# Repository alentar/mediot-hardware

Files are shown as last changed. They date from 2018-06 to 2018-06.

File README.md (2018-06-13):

# RPMS-hardware

## Intro

**MedIOT** project uses the NodeMCU as main embedded system. It is selected nodeMCU as the main platform because it contains an integrated ESP8266MOD wifi module with Arduino nano board. A digital temperature sensor DS18B20 sensor and Pulse sensor is using as inputs to the nodemodule.

## Before get started

 1. Install [Arduino SDK](https://www.arduino.cc/en/Main/Software) and [ESP8266 Board Manager](https://github.com/esp8266/Arduino#installing-with-boards-manager)
 
 3. Install following Arduino libraries by `Sketch>Library>Library Manager` ;
	 - Arduino JSON- (by Benoit Blanchan) [Link](https://arduinojson.org/?utm_source=meta&utm_medium=library.properties)
	 - Arduino Mqtt (by Oleg Kevolenko) - [Link](https://github.com/monstrenyatko/ArduinoMqtt)
	 - Arduino LCD I2C Lib - [Link](https://github.com/fdebrabander/Arduino-LiquidCrystal-I2C-library)
	 
 4.  Set the sketch option from `Tools` menu as follows 
 

## Board Configuration
 In this, we are using two sensors, Heart Pulse sensor and Temperature sensor. Pulse sensor is given to A0 input, and Temperature sensor DS18B20 given to GPIO input

For `ESP.Restart()` nodemcu checking the pins for booting. Here we are **boot from the sketch**  So according to the following table  **GPIO0** and **GPIO1** should connected to **3V3 Vcc** and **GPIO15** should connected to **GND** with resistors . 

> if the wdt reset is triggert the board reboots, when it **reboots it
> is checking the state of GPIO0 and GPIO15 and GPIO2**

|GPIO15|GPIO0|GPIO2|Mode|
|--|--|--|--|
|0V|0V|	3.3V|Uart Bootloader||
|0V|3.3V|3.3V|**Boot sketch**||
|3.3V|x|x|SDIO mode (not used for Arduino)|

> **you need to make sure that the pins in the right state when a wtd happens or you call ESP.restart() better you add some delays to
> prevent the wtd from triggering.**

**`Important :
All the above connetions should be made with a 10K resistors`**

## Run the code

 1. Compile and Upload the code to the Nodemcu
 2. Open SerialMonitor
 3. Restart the Nodemcu 
 4. SoftAP WiFi is set on the relevent ip address shown in the serial monitor. *default WiFi SSID*-> `Mediot1`

##  API End Points
API end points of the Sever as follows;

 #### Server default Address: `192.168.4.1:8080`
-----
### Show Server Status

Get the status of the server.

**URL** : `/api/status/`

**Method** : `GET`

**Auth required** : NO

**Permissions required** : None

 Success Response

**Code** : `200 OK`
```json
{
    "status": "ok"
}
```

---
### Set Configurations

Setting the WiFi credentials and API end point of the mqtt server

**URL** : `/api/config/`

**Method** : `POST`

**Auth required** : --

**Permissions required** : --

**Data constraints**

Provide wifi details and api end point.

```json
{
	"ssid":"YOURWIFISSID",
	"password":"YOURWIFIPASSWORD",
	"link":"MQTT_SERVER"
}
```

### Success Response

**Code** : `200 OK`
```json
{
    "status": "ok"
}
```
---
### Save Configuration

Saving the given wifi credentials and end point

**URL** : `/api/finish`

**Method** : `GET`

**Auth required** : NO

**Permissions required** : None

 Success Response

**Code** : `200 OK`
```json
{
    "status": "ok"
}
```

## Board Schemetics

### Schemetic Design

schem

### PCB Design

final

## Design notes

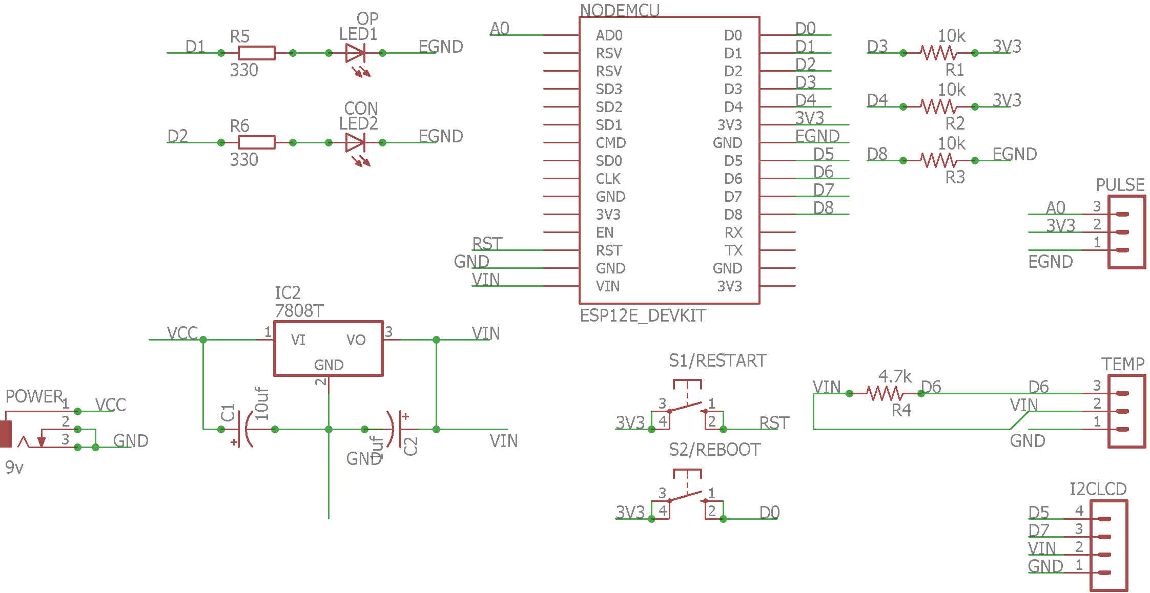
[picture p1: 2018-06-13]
PCB/schem.png

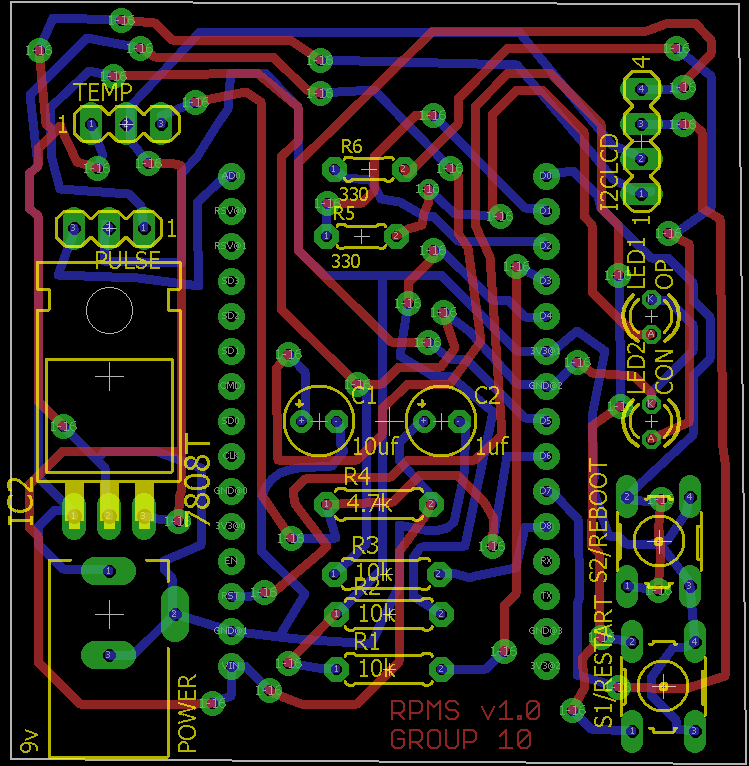
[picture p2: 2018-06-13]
PCB/final.png

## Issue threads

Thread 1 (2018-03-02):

NodeMCU configuration

kasvith, 2018-03-02:
# Problem

NodeMCU should be configured before using the actual web server provided by **mediot**.
This requires achieving followings

- Setup a prefered **SSID** and **Password**  for NodeMCU
- Setup provided Server Url(preferably for **HOST_URI**) by staff

# Solution

These items need to be saved on NodeMCU for continue process.
When you successfully connected to a WiFi NodeMCU will automatically save them in storage and when it restarts it will use previous credentials.

So it only requires to store **HOST_URI** itself on the **EEPROM**. Others are take care by **WiFi** module of **NodeMCU**.

So its required a way to start the Hotspot(aka AccessPoint or AP) of the NodeMCU. Preferably using a **Button**.

## Workflow of Proposed Solution

- Power on NodeMCU
- **Press Button** to **Start Configuration Mode**
- Password and SSID of this Hotspot is given to Staff
- The hotspot will start a simple webserver(RESTful) on **192.168.4.1**
- Staff will use an App after connecting this Hotspot and it will look for **192.168.4.1**.
- Once connected user can set above information with server
- Once finished User may exit Configuration Mode by selecting **Finish** on the App
- This may trigger NoduMCU to stop AccessPoint mode and try to connect given SSID and then send HTTP requests for **HOST_URI** (which set by user)
- Once connected the NodeMCU should show the status of the connection by indicating via LED so staff knows whether setup was successful

# Requirement
- NodeMCU with AccessPoint Mode
- For development purposes use **PostMan**
- NodeMCU should have a field called **SerialNo** which is used by server to provision the device.

kasvith, 2018-03-02:
@edussuriyac @namila007 any comments ?

kasvith, 2018-03-02:
Refer my code for webserver

namila007, 2018-03-02:
starting working on this now . first i have to look up more details about this

Closed 2018-03-18.

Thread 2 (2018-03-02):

Need an Andoid Application for Configurations

kasvith, 2018-03-02:
# Problem
We are creating a NodeMCU Configuration Module in #1
We need a way to communicate with this, so we need to create a App to connect with this **RESTful API**.

# Requirenments
- NodeMCU will start its AccessPoint and user will connect to that with provided password
- Then he opens the App (**Mediot Config** would be fine)
- App will connect to server listens on **192.168.4.1** of the current network (hosted by NodeMCU)
- App will use JSON API to connect and configure followings
  - **SSID**
  - **Password**
  - **Host URI**
- After successfully setting these up, App may exit by touching a button called **Save and Exit**, this will trigger server to terminate itself and start again with provided configurations (you will get an API endpoint for that)

@namila007 must provide a detailed API documentation in **Wiki** Section so @edussuriyac can use them correctly

Meanwhile application can be developed

kasvith, 2018-03-02:
Moved into separate repo

Closed 2018-03-02.

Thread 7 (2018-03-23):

Device authentication

kasvith, 2018-03-23:
This need to be done by sending a request to server with proper information about device. Once authorized server will issue mqtt topics for the device which can be used to connect and send data

**Server endpoints are on the way**

namila007, 2018-05-27:
already done. closes #12

Closed 2018-05-27.

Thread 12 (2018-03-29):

Device Authorization

namila007, 2018-03-29:
Creating device authorization;
RPMS server has a clean device management system. Before any device connect and publish data to server, they need to register themselves to the service.

Endpoint
`POST /api/devices/auth/self`

Sample Request
```json
{
	"mac": "<MACADDRESS OF THE DEVICE>",
	"chipId": "<CHIP ID IF AVALIABLE>"
}
```
mac is the required field here You can poll with server sending above information and based on status determine your next action

wiki link :[ LINK](https://github.com/alentar/rpms-server/wiki/Device-Authorization)

namila007, 2018-05-27:
closes #16

Closed 2018-05-27.

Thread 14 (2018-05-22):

MQTT Connection

namila007, 2018-05-22:
After authorizing the device, it must send to relevant mqqt broker with temp and heart data

Closed 2018-05-27.

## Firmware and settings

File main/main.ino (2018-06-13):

#include <ESP8266WiFi.h>
#include <WiFiClient.h>
#include <ESP8266WebServer.h>
#include <ArduinoJson.h>
#include <EEPROM.h>
#include <String.h>
#include "FS.h"
#include <MQTTClient.h>
#include <OneWire.h>
#include <DallasTemperature.h>
#include <LiquidCrystal_I2C.h>
#include <Wire.h>


#define HEARTPIN A0
#define GREENLED D1
#define REDLED D2
#define ONE_WIRE_BUS D6



const char *AUTH_SELF = "";

char ST_SSID[20];
char ST_PASSWORD[20];
char ST_LINK[20];
char CLIENT_ID[30];
char TOPIC[100];

/* Set these to your desired credentials. */
const char *ssid = "Mediot1";
const char *password = "randompassword";
const char *deviceID = "mediot";


OneWire oneWire(ONE_WIRE_BUS);
DallasTemperature sensors(&oneWire);
LiquidCrystal_I2C lcd(0x3F, 16, 2);  //SDL 7 SCL 5

typedef struct t  {
    unsigned long tStart;
    unsigned long tTimeout;
}timer;

timer pulse_timer = {0, 1000}; //Run every 1 seconds for pulse sensor.
timer temp_timer = {0, 5000}; //5sec for temp

  int UpperThreshold = 518;
  int LowerThreshold = 490;
  int reading = 0;
  bool IgnoreReading = false;
  bool FirstPulseDetected = false;
  unsigned long FirstPulseTime = 0;
  unsigned long SecondPulseTime = 0;
  unsigned long PulseInterval = 0;

MQTTClient client;
WiFiClient wificlient;


/*definitions

*/
void handleStatus();
void handleNotFound();
bool handleSetup();
void handleFinishWizard();
void sendError(char *message, int status);
void configureSoftAP();

bool checkEEPROM();
bool loadConfig();
void EEPROM_wifidata();
bool stationMode();

void mqtt_connect();
boolean authorize();

float getHeartRate();
void sendPulse (float bpm);
void sendTemp(float temp);
float getTemp();
void clearPrintingdigits(int col,int row);
/*
   END OF DEFINITIONS
*/



ESP8266WebServer server(8080);



void setup() {
  //starting eeprom and serial
  Serial.begin(115200);
  EEPROM.begin(512);  //in node EEPROM should init and EEPROM.commit to write.

  pinMode(GREENLED,OUTPUT);
  pinMode(REDLED,OUTPUT);

  Wire.begin(13,14); //Wire.begin(int sda, int scl);
  lcd.begin();   // initializing the LCD
  lcd.backlight(); // Enable or Turn On the backlight
  lcd.setCursor(4, 0);
  lcd.print("RPMS v1.1"); 
  lcd.setCursor(0, 1);
  lcd.print("LOADING...."); // Start Printing
  
  Serial.println("Mounting FS...");
  if (!SPIFFS.begin()) {
    Serial.println("Failed to mount file system");
    return;
  }
  Serial.setDebugOutput(true); //setting debug mode on
   digitalWrite(REDLED,HIGH);
  if (!checkEEPROM()) {
    //starting the AP   
    lcd.setCursor(0, 1);
    lcd.print("CONFIG MODE"); // config mode
    configureSoftAP();

    while (checkEEPROM() != true) {
      //we need to run the sever till the client writes the data to EEPROM
      server.handleClient();
      delay(3000);
    }
    //closing the AP

    WiFi.disconnect();
    WiFi.softAPdisconnect();
    EEPROM.end();
    delay(100);
  }
  else {
    Serial.println("HAS DATA ");
    
    lcd.setCursor(0, 1);
    lcd.print("LOADING CONFIG"); // Start Printing
  
    if (!loadConfig()) {
      Serial.println("Failed to load config file");
    } else {
      Serial.println("Config loaded");
    }
    delay(1000);
    if (!stationMode()) {
      Serial.println("Failed to start Stationary mode");
    } else {
      Serial.println("Stationary mode started");
    }

    //starting MQTT
    
    while (!authorize()){
      delay(500);//client sending post
    }

    sensors.begin(); //start temp sensor
    client.begin(ST_LINK, wificlient); //conecting to mqtt broker

    
  }

}

void loop() {
  
  
    //lcd.clear();
  
   
    delay(50);
    float bpm = (float)getHeartRate();
    float temp = getTemp();
    Serial.println(bpm);
     
  client.loop();
  if (!client.connected()) {
    mqtt_connect();
  }

  
  //lcd.clear();
  if (tCheck(&pulse_timer)) {
     Serial.println(bpm);
     
     lcd.setCursor(0, 0);
      lcd.print("BPM : ");
      clearPrintingdigits(6,0);
      lcd.setCursor(6, 0);
      lcd.print(bpm);
      sendPulse(bpm);
      
      tRun(&pulse_timer);
    }

    if (tCheck(&temp_timer)) {
     
     Serial.println(temp);
      lcd.setCursor(0, 1);
      lcd.print("TEMP: ");
      clearPrintingdigits(6,1);
      lcd.setCursor(6, 1);
      lcd.print(temp);
      sendTemp(temp);
      tRun(&temp_timer);
    }      
    //Serial.println(bpm);

  
  

}

void clearPrintingdigits(int col,int row){
  for(int i=col;i<17;i++){
    lcd.print("");
  }
  
}



/* Sensors
 *  
 */

void sendTemp(float temp){
  Serial.print("send temp: ");
  Serial.println(temp);
  String topic = TOPIC;
  topic += "/type/temperature";
  client.publish(topic, (String)temp);
}

float getTemp() {
  sensors.requestTemperatures();
  return (sensors.getTempCByIndex(0));
}


void sendPulse (float bpm) {
  //This executes every 1000ms.
 
  
  Serial.print("send");
  Serial.println(bpm);
  String topic = TOPIC;
  topic += "/type/bpm";
  client.publish(topic, (String)bpm);
}

bool tCheck (timer *t ) {
  if (millis() > t->tStart + t->tTimeout) {
    return true;    
  }
  return false;
}

void tRun (timer *t) {
    t->tStart = millis();
}

float getHeartRate(){
 

    reading = analogRead(HEARTPIN); 

      // Heart beat leading edge detected.
      if(reading > UpperThreshold && IgnoreReading == false){
        if(FirstPulseDetected == false){
          FirstPulseTime = millis();
          FirstPulseDetected = true;
        }
        else{
          SecondPulseTime = millis();
          PulseInterval = SecondPulseTime - FirstPulseTime;
          FirstPulseTime = SecondPulseTime;
        }
        IgnoreReading = true;
      }

      // Heart beat trailing edge detected.
      if(reading < LowerThreshold){
        IgnoreReading = false;
      }  

      float BPM = (1.0/PulseInterval) * 60.0 * 1000;

      return BPM;

  
}


/*
 * END OF HEART RATE
 */




/*
   Device IDs
*/
boolean authorize() {

  String device_id = String(ESP.getChipId());
  String mac_id = String(WiFi.macAddress());          //Get the response payload

  lcd.clear();
  lcd.setCursor(4, 0);
  lcd.print("RPMS v1.1"); 
  lcd.setCursor(0, 1);
  lcd.print("DEVICE AUTH"); 

  const int httpPort = 3000;
  String host = "192.168.8.100";
  String data = "{\"mac\":\"" + mac_id + "\",\"chipId\":\"" + device_id + "\"}";
  String buffer;
  char json[1000];

  // String* host = ST_LINK;
  if (!wificlient.connect(ST_LINK, httpPort)) {
    Serial.println("connection failed");
    delay(500);
    return false;
  }
  
  Serial.println("Requesting POST: ");
  // Send request to the server:
  wificlient.println("POST /api/devices/auth/self HTTP/1.1");
  wificlient.print("Host: ");
  wificlient.println(ST_LINK);
  wificlient.println("User-Agent: Arduino/1.0");
  wificlient.println("Connection: close");
  wificlient.println("Accept: */*");
  wificlient.println("Content-Type: application/json");
  wificlient.print("Content-Length: ");
  wificlient.println(data.length());
  wificlient.println();
  wificlient.print(data);

  delay(100); // Can be changed
  int counter = 0;

  char results[1500];
  char c ;
  int index = 0;
  while (wificlient.available())
  {
    c = wificlient.read();
    results[index] = c;
    index++;
  }
  results[index] = '\0';
  //Serial.println(results);
  int j = 0;
  for (int i = 430; i < index; i++) {
    json[j] = results[i];
    j++;
  }
  json[j] = '\0';

  Serial.println("closing connection");
  
  const size_t bufferSize = JSON_OBJECT_SIZE(3) + 70;
  DynamicJsonBuffer jsonBuffer(bufferSize);
  JsonObject& root = jsonBuffer.parseObject(json);

  const char* state = root["state"];
  const char* operate = "operate";

 // root.printTo(Serial);
  
  if (strcmp(state, operate) == 0) {
    lcd.clear();
    lcd.setCursor(4, 0);
    lcd.print("RPMS v1.1"); 
    lcd.setCursor(0, 1);
    lcd.print("AUTHORIZED"); 
    
    const char* mqttTopic = root["mqttTopic"];
    const char* id = root["id"];
    Serial.println(mqttTopic);
    strcpy(TOPIC, mqttTopic);
    strcpy(CLIENT_ID, id);
    Serial.println(TOPIC);
    delay(1000);
    return true;
  }else{
    delay(4000);
    return false;
  }
  delay(4000);
  return false;




}




/*
   End Device IDs
*/

/*
   START OF STATION MODE
*/
bool checkEEPROM() {

  int mem_loc = 0;
  int value;
  EEPROM.get(mem_loc, value);

  if (value == 1) {
    return true;
  } else {
    return false;
  }
}

bool loadConfig() {
  File configFile = SPIFFS.open("/config.json", "r");
  if (!configFile) {
    Serial.println("Failed to open config file");
    return false;
  }

  size_t size = configFile.size();
  if (size > 1024) {
    Serial.println("Config file size is too large");
    return false;
  }

  // Allocate a buffer to store contents of the file.
  std::unique_ptr<char[]> buf(new char[size]);


  configFile.readBytes(buf.get(), size);

  StaticJsonBuffer<200> jsonBuffer;
  JsonObject& json = jsonBuffer.parseObject(buf.get());

  if (!json.success()) {
    Serial.println("Failed to parse config file");
    return false;
  }

  
  
  json.printTo(Serial);
  const char* ssid = json["ssid"];
  const char*  pass = json["password"];
  const char*  link = json["link"];
  delay(10);
  strcpy(ST_PASSWORD, pass);
  strcpy(ST_LINK, link);
  strcpy(ST_SSID, ssid);
  delay(10);

  Serial.print("Loaded ssid: ");
  Serial.println(ST_SSID);
  Serial.print("Loaded password: ");
  Serial.println(ST_PASSWORD);
  Serial.print("Loaded link: ");
  Serial.println(ST_LINK);
  return true;
}

bool stationMode() {
  WiFi.disconnect();
  WiFi.softAPdisconnect();
  delay(100);
  WiFi.persistent(false);
  WiFi.mode(WIFI_OFF);
  WiFi.mode(WIFI_STA);
  if (WiFi.begin(ST_SSID, ST_PASSWORD)) {
    return true;
  } else {
    return false;
  }

}


/*
   END OF STATION MODE
*/






/*             Start of WIFI SERVER
  /api/status for check
  /api/config for configurations
  /api/finish/wizard for end

*/
void configureSoftAP() {
  //dc all
  WiFi.disconnect();
  WiFi.softAPdisconnect();

  Serial.println();
  Serial.print("Configuring access point...");
  /* You can remove the password parameter if you want the AP to be open. */
  WiFi.mode(WIFI_AP);
  delay(100);

  Serial.println(WiFi.softAP(ssid) ? "Ready" : "Failed!");

  IPAddress myIP = WiFi.softAPIP();
  Serial.print("AP IP address: ");
  Serial.println(myIP);
  server.on("/api/status", handleStatus);
  server.on("/api/config", handleSetup);
  server.on("/api/finish", handleFinishWizard);
  server.onNotFound(handleNotFound);
  server.begin();
  Serial.println("HTTP server started");
}


void handleStatus() {
  StaticJsonBuffer<300> JSONbuffer;   //Declaring static JSON buffer
  JsonObject& JSONencoder = JSONbuffer.createObject();

  JSONencoder["status"] = "OK";
  char JSONmessageBuffer[300];
  JSONencoder.prettyPrintTo(JSONmessageBuffer, sizeof(JSONmessageBuffer));

  server.send(200, "application/json", JSONmessageBuffer);
}

void handleNotFound() {
  StaticJsonBuffer<300> JSONbuffer;   //Declaring static JSON buffer
  JsonObject& JSONencoder = JSONbuffer.createObject();

  JSONencoder["message"] = "Not Found";
  char JSONmessageBuffer[300];
  JSONencoder.prettyPrintTo(JSONmessageBuffer, sizeof(JSONmessageBuffer));

  server.send(404, "application/json", JSONmessageBuffer);
}

bool handleSetup() {
  StaticJsonBuffer<300> JSONbuffer;   //Declaring static JSON buffer
  JsonObject& root = JSONbuffer.parseObject(server.arg("plain"));

  if (!root.success()) {
    sendError("Parsing json failed", 500);
  }

  if (!root.containsKey("ssid")) {
    sendError("SSID not found", 500);
  }

  if (!root.containsKey("password")) {
    sendError("Password not found", 500);
  }

  if (!root.containsKey("link")) {
    sendError("API link not found", 500);
  }

  File configFile = SPIFFS.open("/config.json", "w");
  if (!configFile) {
    Serial.println("Failed to open config file for writing");
    return false;
  }

  root.printTo(configFile);
  server.send(200, "application/json", "{\"status\":\"ok\"}");
  delay(500);
  return true;
}

void handleFinishWizard() {

  int addr = 0;
  int configSaved = 1;
  server.send(200, "application/json", "{\"status\":\"done\"}");
  delay(500);
  EEPROM.put(addr, configSaved);
  delay(100);
  EEPROM.commit();

  ESP.restart(); // restart to work with saved credentials
}


void sendError(char *message, int status) {
  StaticJsonBuffer<300> JSONbuffer;   //Declaring static JSON buffer
  JsonObject& JSONencoder = JSONbuffer.createObject();

  JSONencoder["message"] = message;
  char JSONmessageBuffer[300];
  JSONencoder.prettyPrintTo(JSONmessageBuffer, sizeof(JSONmessageBuffer));

  server.send(status, "application/json", JSONmessageBuffer);
}

/*             END OF WIFI SERVER               */


/*
   START MQTT CLIENT
*/

void mqtt_connect() {

  Serial.print("checking wifi...");
  while (WiFi.status() != WL_CONNECTED) {
    Serial.println("Wifi disconnected, connecting again");
    lcd.setCursor(0, 1);
    lcd.print("WIFI DISCONNECTED"); // Start Printing
    Serial.print(".");
    delay(1000);
  }

  Serial.println("Connecting to Mqtt Server");
  Serial.println(CLIENT_ID);

  lcd.clear();
  lcd.setCursor(4, 0);
  lcd.print("RPMS v1.1"); 
  lcd.setCursor(0, 1);
  lcd.print("MQTT CONNECTING"); // Start Printing
  while (!client.connect(CLIENT_ID, CLIENT_ID, "none")) {
    Serial.print(".");
    delay(1000);
  }
  Serial.println("\nConnected");

  lcd.clear();
  
  digitalWrite(REDLED,LOW);
  digitalWrite(GREENLED,HIGH);
}


/*
   END OF MQTT CLIENT
*/

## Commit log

2018-03-17 EEPROM PRINT
2018-03-18 MQQT implemented
    issue #4 tested
    [main.ino]
2018-03-27 added error for json object `password`
    [main.ino]
2018-05-23 led notification :smirk:
2018-06-09 sensor done
2018-06-13 schemetics added
    [board2.GBL, board2.GBO, board2.GBP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]
2018-06-13 schematics :rocket:
